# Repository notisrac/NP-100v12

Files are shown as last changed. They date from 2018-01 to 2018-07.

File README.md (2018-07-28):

# NP-100v12
My take on the [NP-100v12](http://diyaudioprojects.com/Solid/12AU7-IRF510-LM317-Headamp/) headphone amp (also it has a [GrubDac](http://www.diyforums.org/GrubDAC/GrubDACoverview.php) built in)
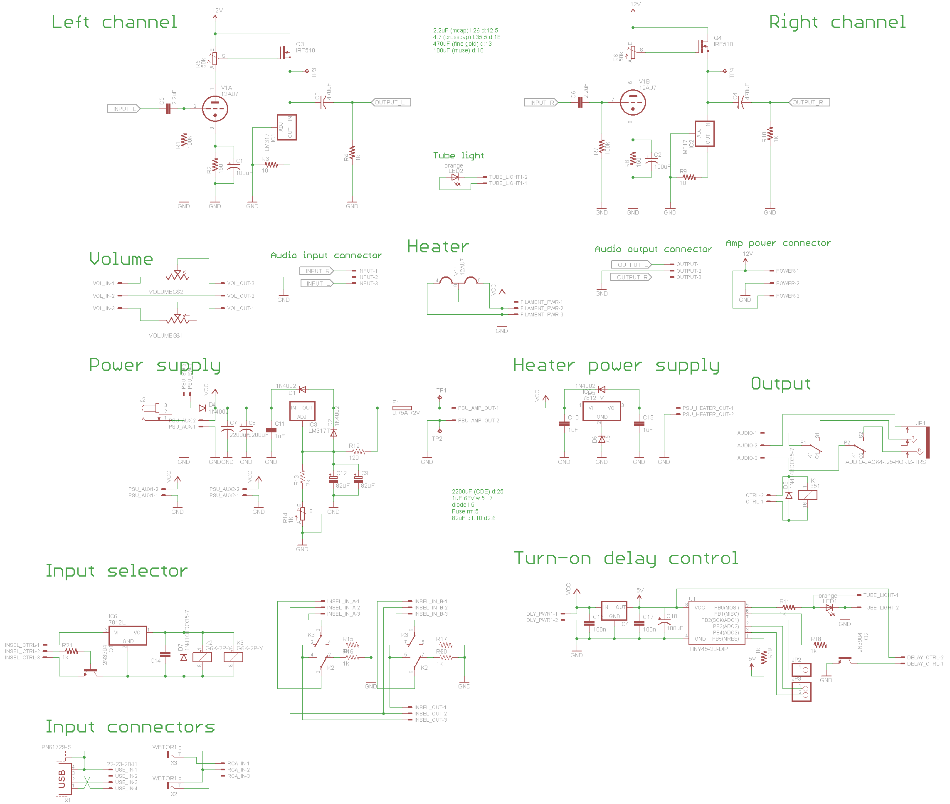
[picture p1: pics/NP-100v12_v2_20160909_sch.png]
Schematic

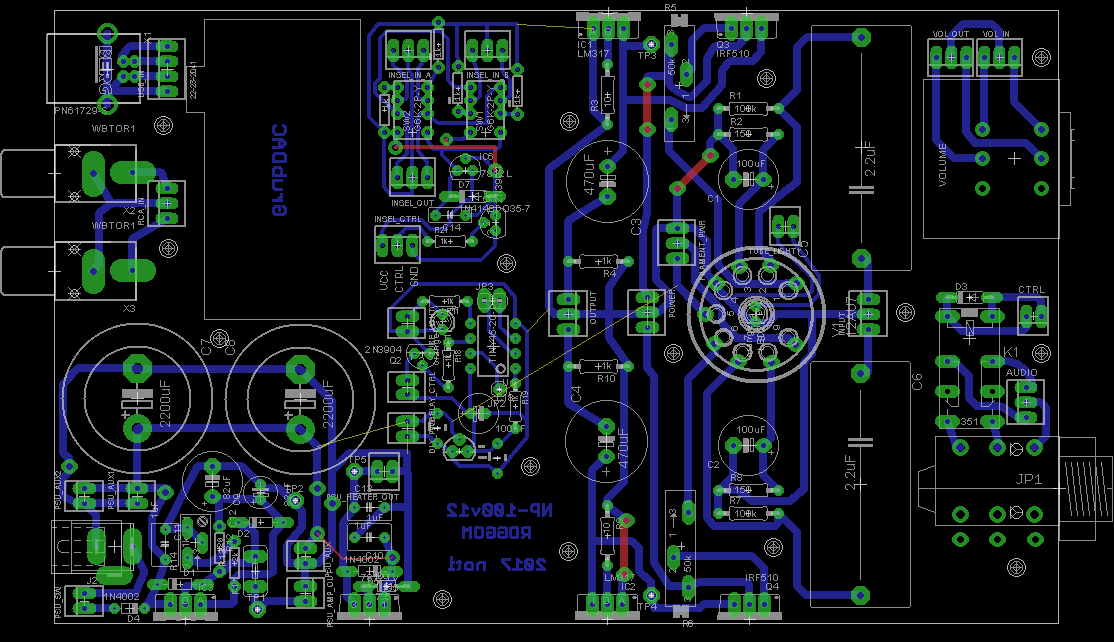
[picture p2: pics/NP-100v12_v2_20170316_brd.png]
Layout


Analytics (https://github.com/igrigorik/ga-beacon)

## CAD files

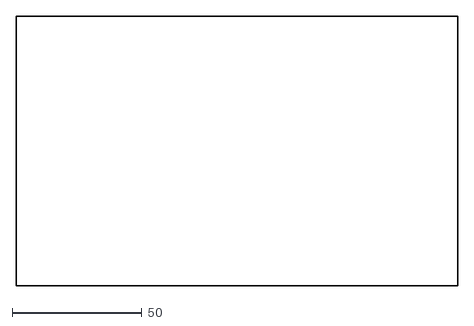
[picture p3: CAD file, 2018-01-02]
CADFiles/case/case_outline.dxf
170.0 x 104.0

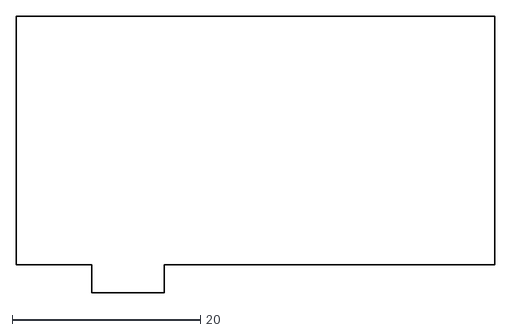
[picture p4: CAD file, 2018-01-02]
CADFiles/grubdac/grubdac.dxf
50.8 x 29.4

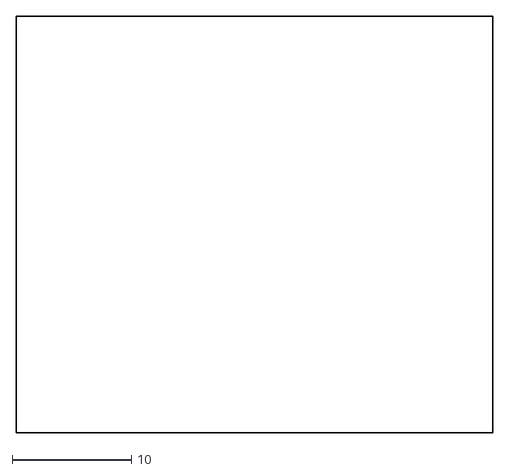
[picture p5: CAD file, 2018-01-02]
CADFiles/vumeter/vumeter.dxf
40.0 x 35.0

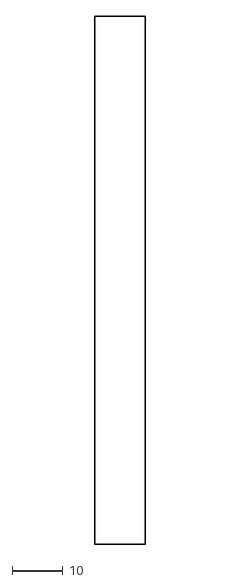
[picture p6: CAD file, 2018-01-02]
CADFiles/case/case_outline_front.dxf
10.0 x 104.0

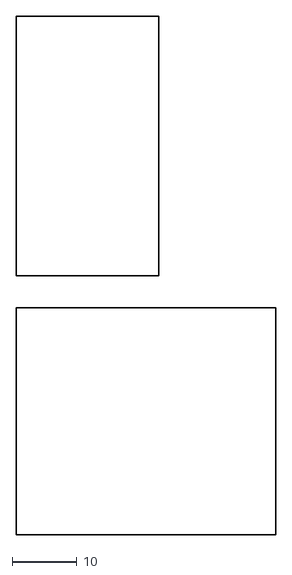
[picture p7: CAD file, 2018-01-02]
CADFiles/case/case_outline_knob_vu.dxf
40.0 x 80.0

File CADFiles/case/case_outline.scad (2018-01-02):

rotate(0,0,0)
// case
polygon([
    [0, 0],
    [0, 104],
    [170, 104],
    [170, 0]
]);
// front panel
translate([170,0,0]) {
    polygon([
        [0, 0],
        [0, 104],
        [10, 104],
        [10, 0]
    ]);
}

// vu meter
translate([181,20,0]) {
    polygon([
        [0, 0],
        [0, 35],
        [40, 35],
        [40, 0]
    ]);
}

// volume knob
translate([181,60,0]) {
    polygon([
        [0, 0],
        [0, 40],
        [22, 40],
        [22, 0]
    ]);
}

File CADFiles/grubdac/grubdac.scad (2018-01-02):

rotate(0,0,0)
// grub dac board
polygon([
    [0, 0],
    [0, 26.40],
    [50.80, 26.40],
    [50.80, 0]
]);
// usb connector
polygon([
    [8.01, 0],
    [8.01, -3],
    [15.71, -3],
    [15.71, 0]
]);

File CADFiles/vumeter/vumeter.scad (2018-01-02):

rotate(0,0,0)
// vu meter
polygon([
    [0, 0],
    [0, 35],
    [40, 35],
    [40, 0]
]);

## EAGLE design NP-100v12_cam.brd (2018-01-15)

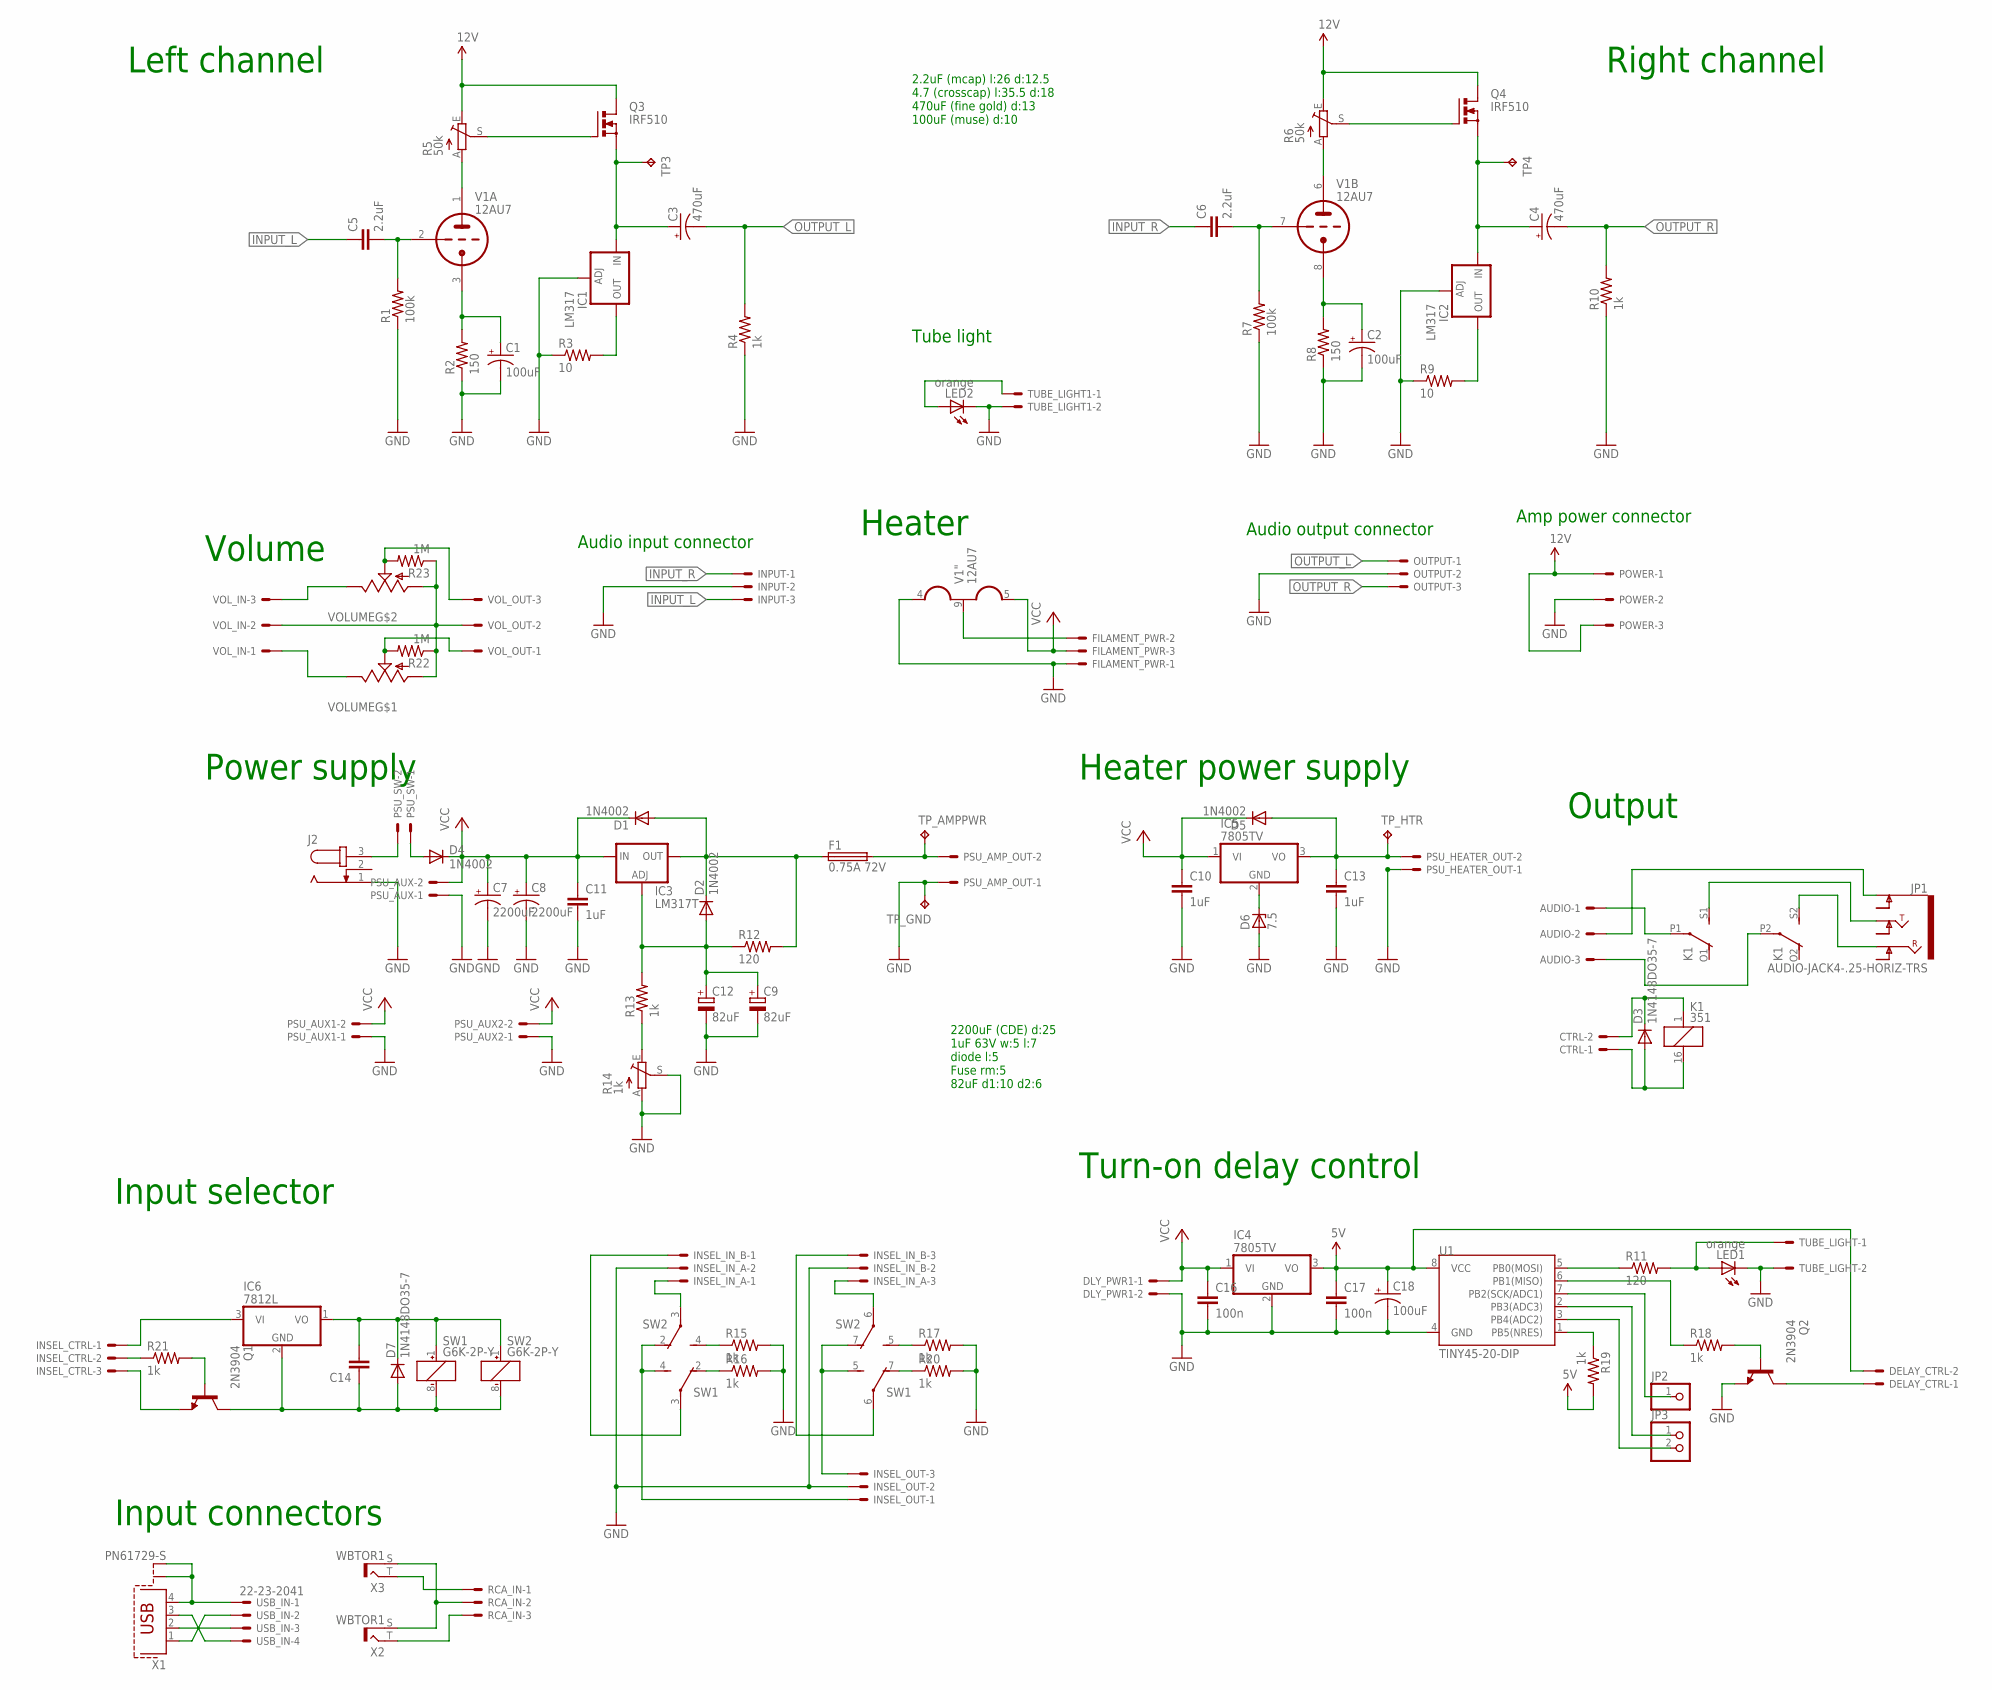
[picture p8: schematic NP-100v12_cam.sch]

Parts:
AUDIO: 22-23-2031
C1, C2: 100uF; E5-10,5
C3, C4: 470uF; E5-13
C5, C6: 2.2uF; C37.5B19
C7, C8: 2200uF; EB25D
C9: 82uF; E2,5-6
C10, C11, C13: 1uF; C5B4.5
C12: 82uF; E5-10,5
C14: C5/2.5; C5B2.5
C16, C17: 100n; CAP-PTH-5MM
C18: 100uF; E2,5-7
CTRL: 22-23-2021
D1, D2, D5: 1N4002; D-7.5
D3, D7: 1N4148DO35-7; DO35-7
D4: 1N4002; D-5
D6: 7.5; DO34Z7
DELAY_CTRL: 22-23-2021
DLY_PWR1: 22-23-2021
F1: 0.75A 72V; TE5
FILAMENT_PWR: 22-23-2031
IC1, IC2: LM317; 317TS
IC3: LM317T; 317TS
IC4, IC5: 7805TV; TO220V
IC6: 7812L; TO92
INPUT: 22-23-2031
INSEL_CTRL: 22-23-2031
INSEL_IN_A: 22-23-2031
INSEL_IN_B: 22-23-2031
INSEL_OUT: 22-23-2031
J2: JACK-PLUG0; SPC4077
JP1: AUDIO-JACK4-.25-HORIZ-TRS; AUDIO-JACK-.25-INCH-HORIZ-PTH
JP2: PINHD-1X1; 1X01
JP3: PINHD-1X2; 1X02
K1: 351
LED1, LED2: orange; LED3MM
OUTPUT: 22-23-2031
POWER: 22-23-2031
PSU_AMP_OUT: 22-23-2021
PSU_AUX, PSU_AUX1, PSU_AUX2: 22-23-2021
PSU_HEATER_OUT: 22-23-2021
PSU_SW: 22-23-2021
Q1, Q2: 2N3904; TO92
Q3, Q4: IRF510; TO220BV
R1, R7: 100k; 0207/10
R2, R8: 150; 0207/10
R3, R9: 10; 0207/10
R4, R10: 1k; 0207/10
R5, R6: 50k; SP19L
R11: 120; 0204/7
R12: 120; AXIAL-0.3
R13, R15, R16, R17, R20: 1k; AXIAL-0.3
R14: 1k; S64Y
R18, R19, R21: 1k; 0204/7
R22, R23: 1M; 0207/10
RCA_IN: 22-23-2031
SW1, SW2: G6K-2P-Y
TP3, TP4: TPPAD1-17; P1-17
TP_AMPPWR: TPPAD1-17; P1-17
TP_GND: TPPAD1-17; P1-17
TP_HTR: TPPAD1-17; P1-17
TUBE_LIGHT, TUBE_LIGHT1: 22-23-2021
U1: TINY45-20-DIP; DIP08
USB_IN: 22-23-2041
V1: 12AU7; NOVAL
VOLUME: ALPS_BLUE; ALPS_RK27
VOL_IN: 22-23-2031
VOL_OUT: 22-23-2031
X1: PN61729-S
X2, X3: WBTOR1

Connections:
5V: C17.1, C18.+, DELAY_CTRL.2, IC4.3 (VO), R19.2, U1.8 (VCC)
12V: POWER.1, POWER.3, Q3.D, Q4.D, R5.E, R6.E
GND: C1.-, C2.-, C7.-, C8.-, C9.-, C10.2, C11.2, C12.-, C13.2, C16.2, C17.2, C18.-, D6.A, DLY_PWR1.2, FILAMENT_PWR.1, IC1.1 (ADJ), IC2.1 (ADJ), IC4.2 (GND), INPUT.2, INSEL_IN_A.2, INSEL_IN_B.2, INSEL_OUT.2, J2.1, LED1.K (C), LED2.K (C), OUTPUT.2, POWER.2, PSU_AMP_OUT.1, PSU_AUX.1, PSU_AUX1.1, PSU_AUX2.1, PSU_HEATER_OUT.1, Q2.3 (E), R1.1, R2.1, R3.1, R4.1, R7.1, R8.1, R9.1, R10.1, R14.A, R14.S, R15.P$2 (2), R16.P$2 (2), R17.P$2 (2), R20.P$2 (2), TP_GND.TP, TUBE_LIGHT.2, TUBE_LIGHT1.2, U1.4 (GND), V1.4 (H1)
INPUT_L: C5.1, INPUT.3
INPUT_R: C6.1, INPUT.1
unnamed: C5.2, R1.2, V1.2 (TG)
unnamed: C1.+, R2.2, V1.3 (TK)
unnamed: R5.A, V1.1 (TA)
unnamed: Q3.G, R5.S
unnamed: C3.+, IC1.3 (IN), Q3.S, TP3.TP
unnamed: IC1.2 (OUT), R3.2
unnamed: C6.2, R7.2, V1.7 (TG)
unnamed: R11.1, U1.5 (PB0(MOSI))
unnamed: IC2.2 (OUT), R9.2
unnamed: C2.+, R8.2, V1.8 (TK)
unnamed: R6.A, V1.6 (TA)
unnamed: Q4.G, R6.S
unnamed: C4.+, IC2.3 (IN), Q4.S, TP4.TP
unnamed: D6.C, IC5.2 (GND)
unnamed: D1.A, D2.C, F1.1, IC3.2 (OUT), R12.P$2 (2)
unnamed: F1.2, PSU_AMP_OUT.2, TP_AMPPWR.TP
unnamed: C9.+, C12.+, D2.A, IC3.1 (ADJ), R12.P$1 (1), R13.P$2 (2)
unnamed: R13.P$1 (1), R14.E
unnamed: C13.1, D5.A, IC5.3 (VO), PSU_HEATER_OUT.2, TP_HTR.TP
unnamed: FILAMENT_PWR.2, V1.9 (H2)
unnamed: AUDIO.1, K1.P1
unnamed: CTRL.1, D3.A, K1.16 (2)
unnamed: R15.P$1 (1), SW2.4 (S)
unnamed: LED2.A, TUBE_LIGHT1.1
unnamed: C14.2, D7.C, IC6.1 (VO), SW1.1 (+), SW2.1 (+)
unnamed: R16.P$1 (1), SW1.2 (O)
unnamed: AUDIO.3, K1.P2
unnamed: JP1.TIP, K1.S1 (S)
unnamed: AUDIO.2, JP1.SLEEVE (EARTH)
unnamed: JP1.RING, K1.S2 (S)
unnamed: VOLUME.I2 (3), VOL_IN.3
unnamed: R22.1, R23.1, VOLUME.G1 (1), VOLUME.G2 (1), VOL_IN.2, VOL_OUT.2
unnamed: VOLUME.I1 (3), VOL_IN.1
unnamed: R23.2, VOLUME.O2 (2), VOL_OUT.3
unnamed: R22.2, VOLUME.O1 (2), VOL_OUT.1
unnamed: J2.3, PSU_SW.2
unnamed: CTRL.2, D3.C, K1.1
unnamed: LED1.A, R11.2, TUBE_LIGHT.1
unnamed: R17.P$1 (1), SW2.5 (S)
unnamed: R18.1, U1.6 (PB1(MISO))
unnamed: Q2.2 (B), R18.2
unnamed: DELAY_CTRL.1, Q2.1 (C)
unnamed: JP2.1, U1.7 (PB2(SCK/ADC1))
unnamed: R19.1, U1.1 (PB5(NRES))
unnamed: JP3.1, U1.2 (PB3(ADC3))
unnamed: JP3.2, U1.3 (PB4(ADC2))
unnamed: D4.A, PSU_SW.1
unnamed: R20.P$1 (1), SW1.7 (O)
unnamed: INSEL_IN_A.1, SW2.3
unnamed: INSEL_IN_A.3, SW2.6
unnamed: INSEL_IN_B.1, SW1.3
unnamed: INSEL_IN_B.3, SW1.6
unnamed: INSEL_OUT.3, SW1.5 (S), SW2.7 (O)
unnamed: INSEL_OUT.1, SW1.4 (S), SW2.2 (O)
unnamed: Q1.2 (B), R21.2
unnamed: IC6.3 (VI), INSEL_CTRL.1
unnamed: INSEL_CTRL.2, R21.1
unnamed: INSEL_CTRL.3, Q1.3 (E)
unnamed: C14.1, D7.A, IC6.2 (GND), Q1.1 (C), SW1.8 (-), SW2.8 (-)
unnamed: RCA_IN.2, X2.S, X3.S
unnamed: RCA_IN.1, X3.T
unnamed: RCA_IN.3, X2.T
unnamed: USB_IN.1, X1.4, X1.S1, X1.S2
unnamed: USB_IN.4, X1.3
unnamed: USB_IN.3, X1.2
unnamed: USB_IN.2, X1.1
OUTPUT_L: C3.-, OUTPUT.1, R4.2
OUTPUT_R: C4.-, OUTPUT.3, R10.2
VCC: C7.+, C8.+, C10.1, C11.1, C16.1, D1.C, D4.C, D5.C, DLY_PWR1.1, FILAMENT_PWR.3, IC3.3 (IN), IC4.1 (VI), IC5.1 (VI), PSU_AUX.2, PSU_AUX1.2, PSU_AUX2.2, V1.5 (H3)

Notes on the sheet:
2200uF (CDE) d:25 1uF 63V w:5 l:7 diode l:5 Fuse rm:5 82uF d1:10 d2:6
2.2uF (mcap) l:26 d:12.5 4.7 (crosscap) l:35.5 d:18 470uF (fine gold) d:13 100uF (muse) d:10
Left channel
Right channel
Volume
Heater
Power supply
Heater power supply
Turn-on delay control
Output
Audio input connector
Audio output connector
Amp power connector
Tube light
Input selector
Input connectors

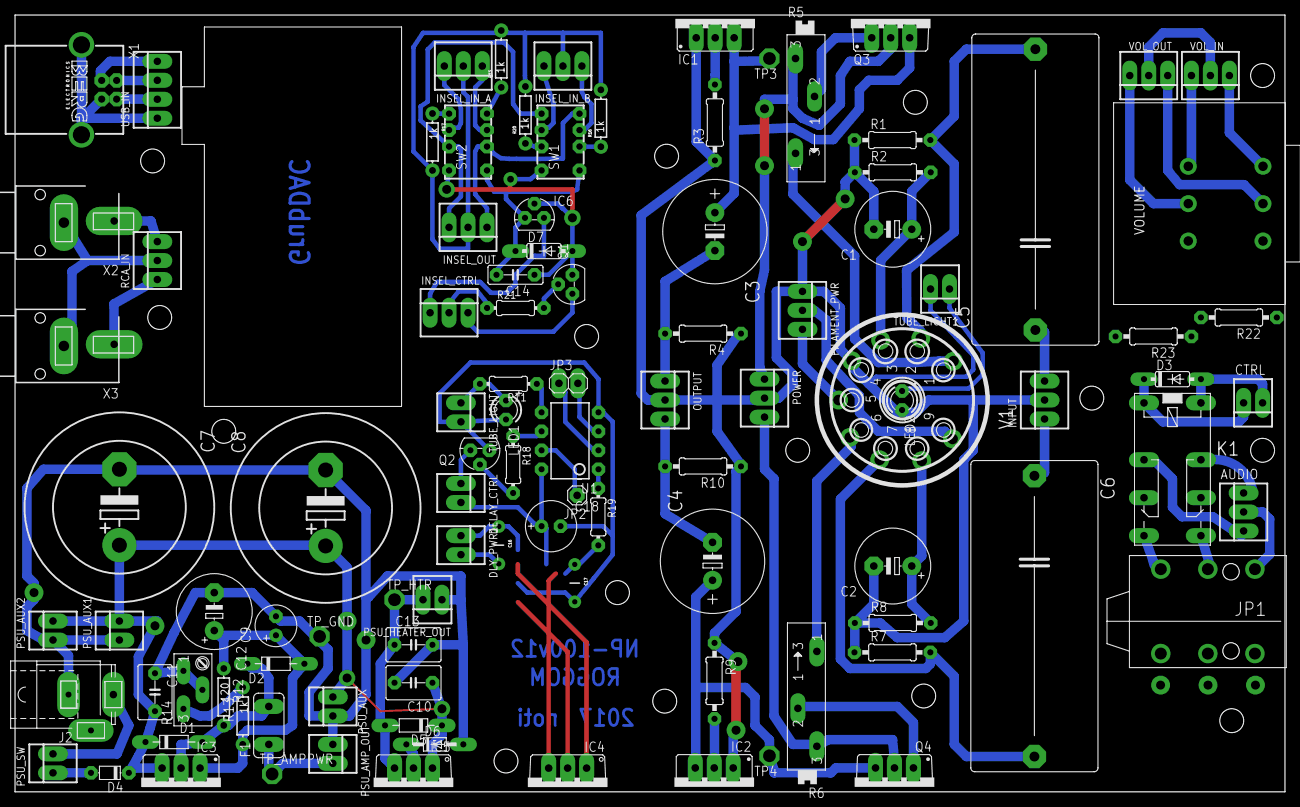
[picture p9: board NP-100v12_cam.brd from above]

Board: 2 copper layers, 170.0 x 104.0 mm, 102 parts (0 on the bottom side), 74 nets.

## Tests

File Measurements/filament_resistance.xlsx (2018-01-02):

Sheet: Munka1
V | mA | Ohm
6.60 | 293.26 | 22.50
7.87 | 342.13 | 23.01
8.49 | 342.13 | 24.81
8.65 | 342.13 | 25.29
8.90 | 342.13 | 26.01
8.90 | 342.13 | 26.01
9.24 | 342.13 | 27.00
9.50 | 342.13 | 27.77
9.65 | 342.13 | 28.20
9.74 | 293.26 | 33.20
9.85 | 342.13 | 28.80
9.81 | 342.13 | 28.67
9.75 | 342.13 | 28.50
9.50 | 342.13 | 27.77
9.49 | 293.26 | 32.35
9.57 | 342.13 | 27.99
9.57 | 293.26 | 32.65
9.49 | 293.26 | 32.35
9.50 | 293.26 | 32.40
9.60 | 342.13 | 28.07
9.63 | 293.26 | 32.85
9.75 | 342.13 | 28.50
9.66 | 342.13 | 28.24
9.94 | 293.26 | 33.90
10.22 | 342.13 | 29.87
10.34 | 342.13 | 30.21
10.47 | 342.13 | 30.60
10.54 | 342.13 | 30.81
10.67 | 342.13 | 31.20
10.75 | 342.13 | 31.41
10.79 | 342.13 | 31.54
10.88 | 342.13 | 31.80
10.87 | 342.13 | 31.76
10.84 | 342.13 | 31.67
10.91 | 342.13 | 31.89
10.91 | 342.13 | 31.89
10.91 | 342.13 | 31.89
10.92 | 342.13 | 31.93
10.94 | 342.13 | 31.97
10.95 | 342.13 | 32.01
10.92 | 342.13 | 31.93
10.95 | 293.26 | 37.35
10.98 | 342.13 | 32.10
11.04 | 342.13 | 32.27
10.98 | 342.13 | 32.10
10.97 | 342.13 | 32.06
10.97 | 342.13 | 32.06
10.87 | 342.13 | 31.76
10.87 | 342.13 | 31.76
10.87 | 342.13 | 31.76
10.87 | 342.13 | 31.76
10.82 | 342.13 | 31.63
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

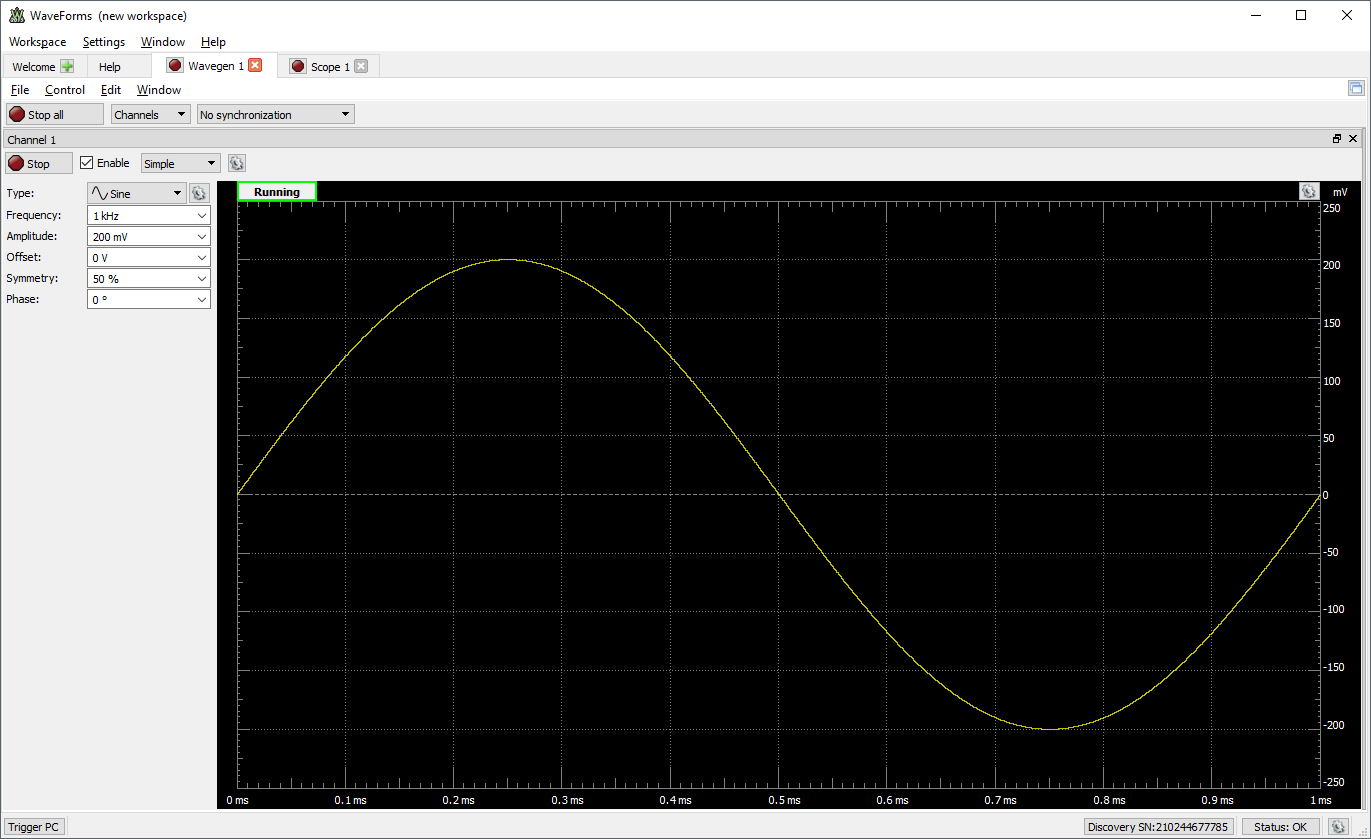
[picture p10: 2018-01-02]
Measurements/200mv_50percent_sine_settings.png

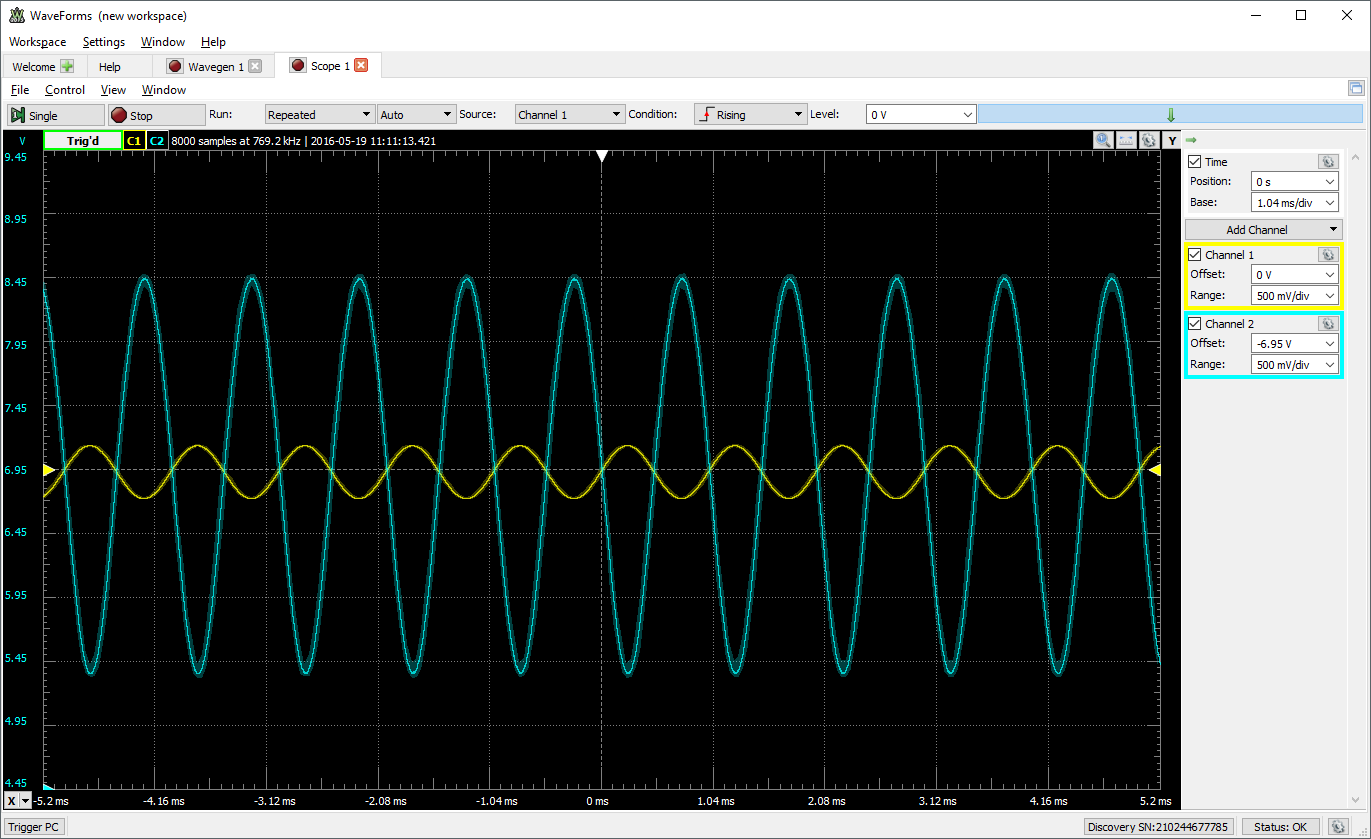
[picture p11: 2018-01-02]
Measurements/200mv_50percent_sine_in_vs_tubeout.png

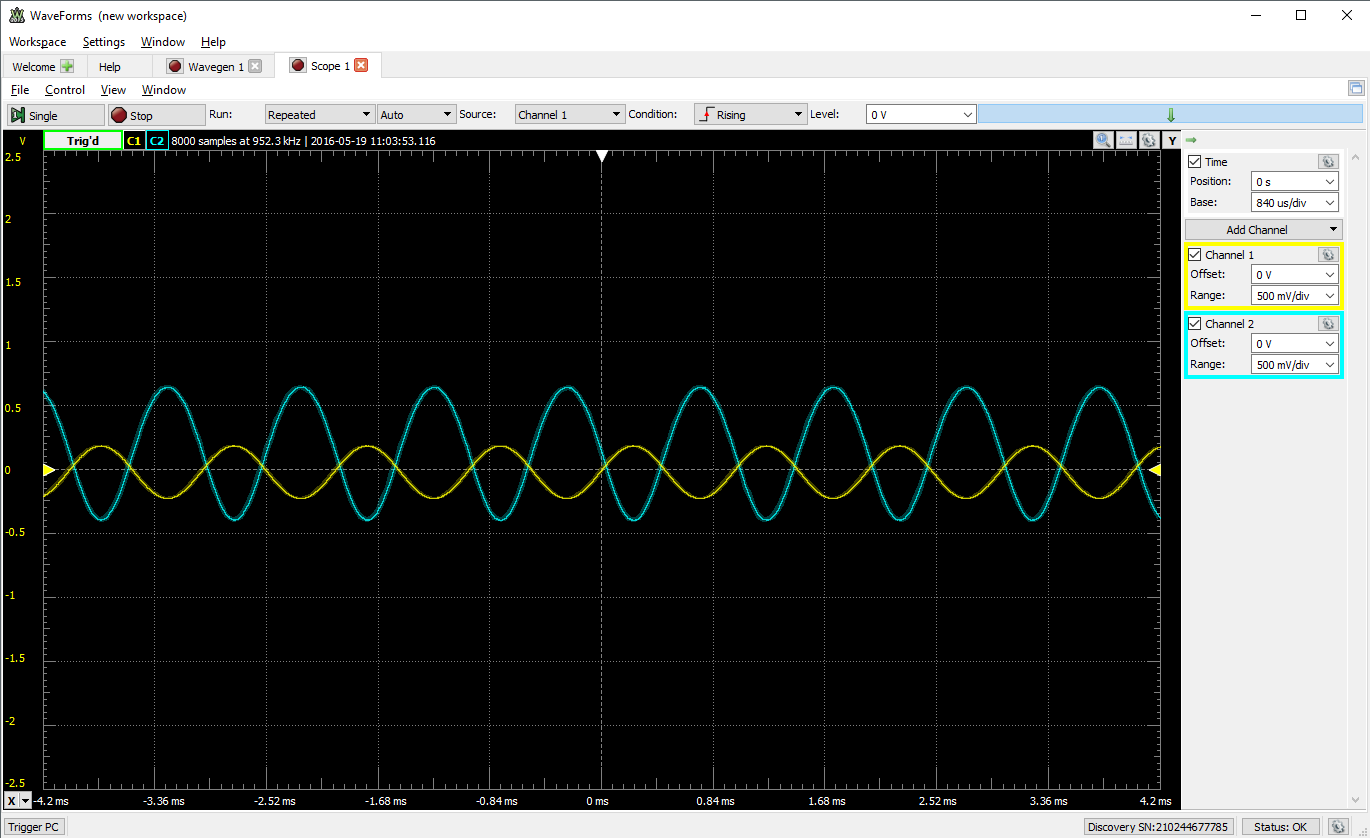
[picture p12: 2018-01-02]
Measurements/200mv_50percent_sine_in_vs_out.png

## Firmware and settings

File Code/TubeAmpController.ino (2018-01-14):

/*
 * Tube amp controller
 * Controlls the tube led and the output relay.
 * noti, 2017
 *
 */


uint8_t pinLed = 0;
uint8_t pinRelay = 1;
unsigned long elapsedTime = 0;


void cosine_pulse(int pin, float time_step, int pause) {
	for (float t = 0; t < 2 * PI; t += time_step) {
		float value = (cos(t - PI)*0.5 + 0.5) * 250;
		analogWrite(pin, value + 5);
		delay(pause);
	}
}

void setup()
{
	pinMode(pinLed, OUTPUT);
	pinMode(pinRelay, OUTPUT);

	digitalWrite(pinLed, LOW);
	digitalWrite(pinRelay, LOW);
}

void loop()
{
	elapsedTime = millis();
	if (elapsedTime < 60000)
	{
		cosine_pulse(pinLed, 0.0025, 1);
	}
	else
	{
		digitalWrite(pinRelay, HIGH);
		digitalWrite(pinLed, HIGH);
	}
}

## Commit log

2018-01-13 - Added resistor between the wiper and ground of the volume pot
    - Added missing ground connection to the volume pot
    [NP-100v12_cam.brd, NP-100v12_cam.sch]
2018-01-14 - Added code for the turn on delay
    - Added arduino/visual micro/visual studio specific info to the gitignore file
    [NP-100v12_cam.brd]
2018-01-15 - Renamed the test points to reflect their function
    [NP-100v12_cam.brd, NP-100v12_cam.sch]

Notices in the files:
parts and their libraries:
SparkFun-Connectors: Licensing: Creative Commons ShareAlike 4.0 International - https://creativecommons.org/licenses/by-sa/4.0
